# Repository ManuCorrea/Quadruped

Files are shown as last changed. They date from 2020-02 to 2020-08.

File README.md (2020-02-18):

# RL Quadruped
This project is a robotic platform to use for education, development and research. 
Objectives: **democratize robotics** and **sim-to-real research**.



## Installation

If using stable baselines:

```
sudo apt-get update && sudo apt-get install cmake libopenmpi-dev python3-dev zlib1g-dev
```

```
pip3 install -r requeriments.txt
```

## Bill of Materials
* Nvidia Jetson Nano
* Arduino Mega
* TinyFPGA BX
* 12 x micro gear dc motors with encoders
* 2 x servos
* ADNS 3080 optical flow sensor
* GY-521
* 7-12V LiPo battery
* 10 x 3D printer endstops
### Tools
* 3D printer
* Soledering iron and solder wire
* M3 screws, nuts and self-locking nuts

## Building

For details and images you can check my [hackster project](https://www.hackster.io/_ManuCorrea_/rl-quadruped-0afbc3)

## Contributing
Pull requests are welcome. For major changes, please open an issue first to discuss what you would like to change.

Feel free to [contact me](https://twitter.com/_ManuCorrea_) directly if you are interested in the project.

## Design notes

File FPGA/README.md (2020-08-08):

# Description
Current used board is a TinyFPGA BX. For a efficient and fast motor control we should make a module based on a bigger FPGA/CPLD.

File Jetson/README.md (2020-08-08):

# Description
Here you have different functions to communicate with Arduino Mega by USB Serial.

## TODO Upgrades
- [ ] Check extreme cases and robustness.
- [ ] Add simplier functions (here and in Arduino) to ask for a certain joint/s instead of all
- [ ] Check how SPI performs and implement it in SPI if it has better results.

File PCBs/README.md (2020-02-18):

# Description
In this folder there will be the KiCad projects of the differents PCBs.

## TODO Upgrades
- [ ] Use a different motor controller IC with PWM to control them with speed variation and implement it in a PCB design.
- [ ] Create PCB for plugging all endstops instead of the protoboard.
- [ ] Create an unique PCB with all electronics.

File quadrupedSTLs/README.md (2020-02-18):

For all parts 0.3 mm layer height is okay and much faster than 0.2 mm.

For gears I recommend using 0.2 mm but each printer is different so you will have to tweak it according to your printer.

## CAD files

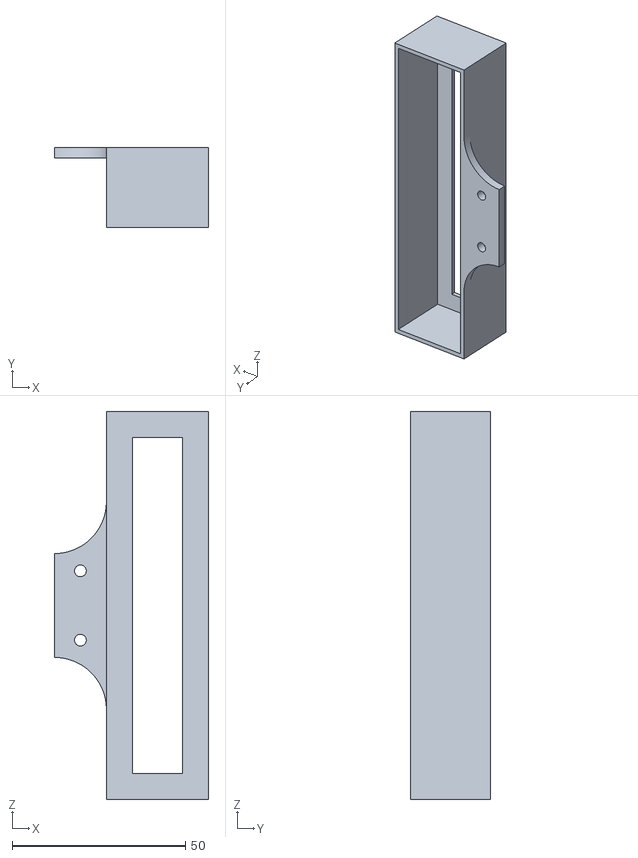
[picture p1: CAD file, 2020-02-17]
quadrupedSTLs/Extras/12V batteryHolder.stl
44.5 x 23.0 x 112.0

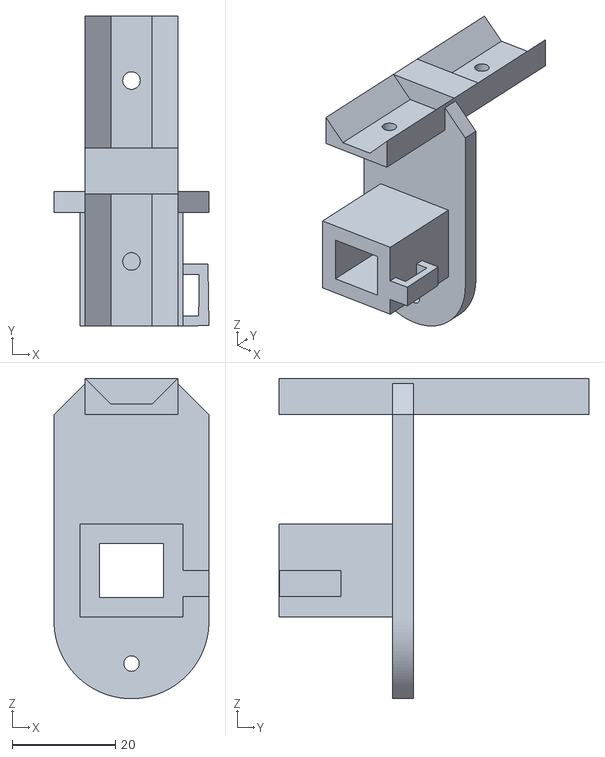
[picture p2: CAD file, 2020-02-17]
quadrupedSTLs/shoulderHorizontal.stl
30.0 x 60.0 x 62.0

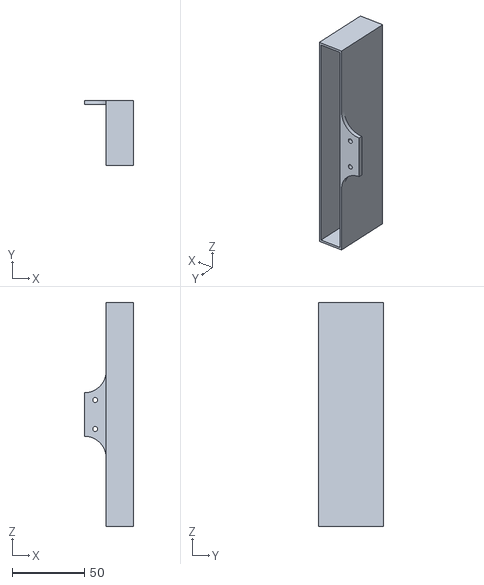
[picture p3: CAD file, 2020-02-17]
quadrupedSTLs/Extras/xiaomiBateryHolder.stl
34.0 x 45.0 x 154.5

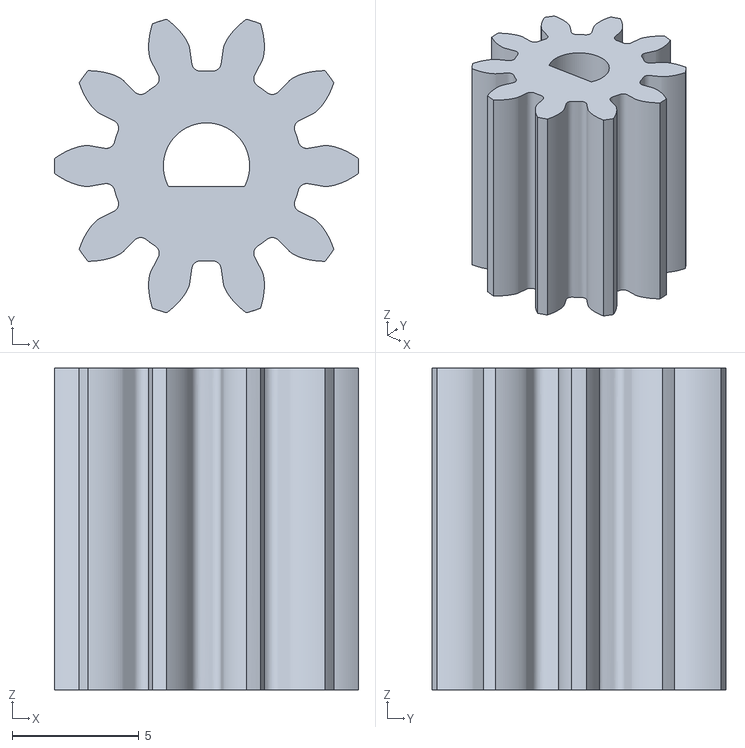
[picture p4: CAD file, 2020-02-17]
quadrupedSTLs/shoulderVerticalGear.stl
12.0 x 11.6 x 12.7

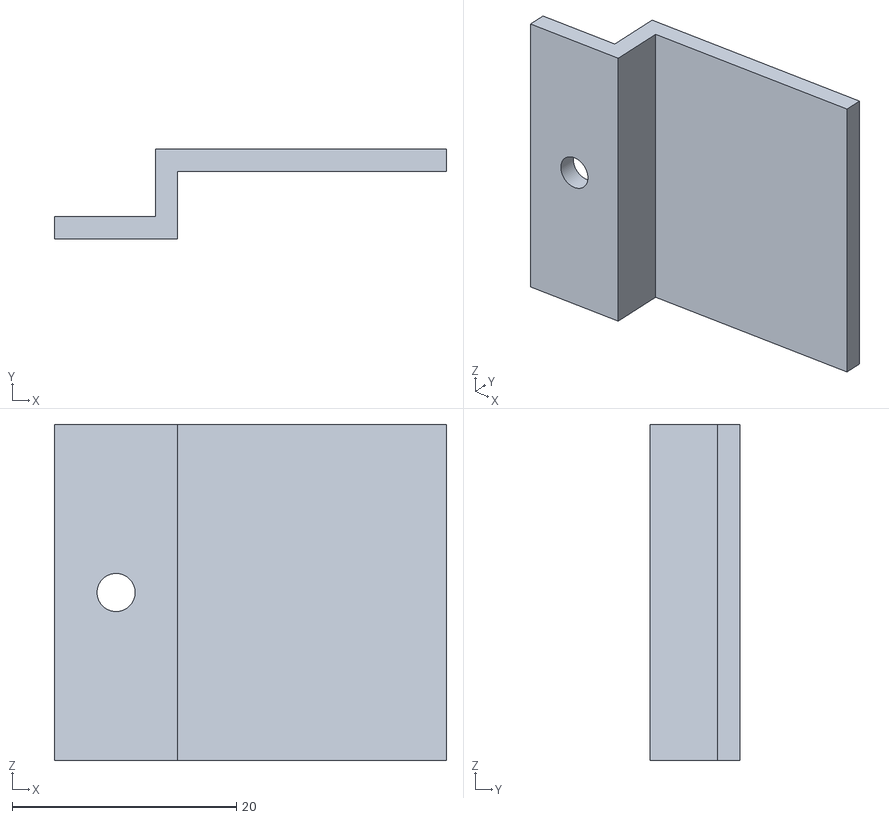
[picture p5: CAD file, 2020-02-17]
quadrupedSTLs/Extras/ADNS_2_servoHolder.stl
35.0 x 8.00 x 30.0

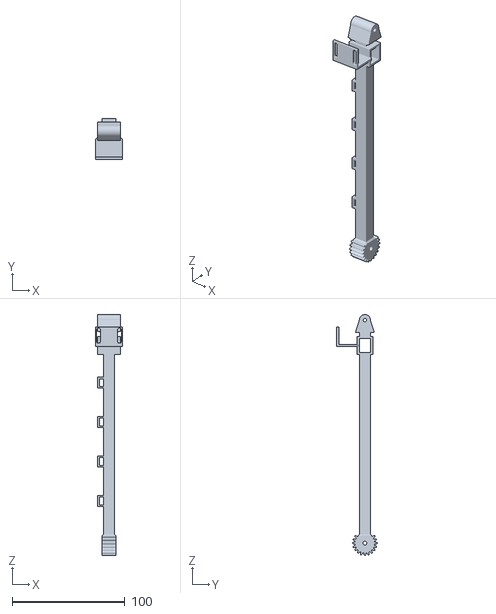
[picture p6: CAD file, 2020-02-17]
quadrupedSTLs/femur.stl
24.0 x 36.0 x 213.7

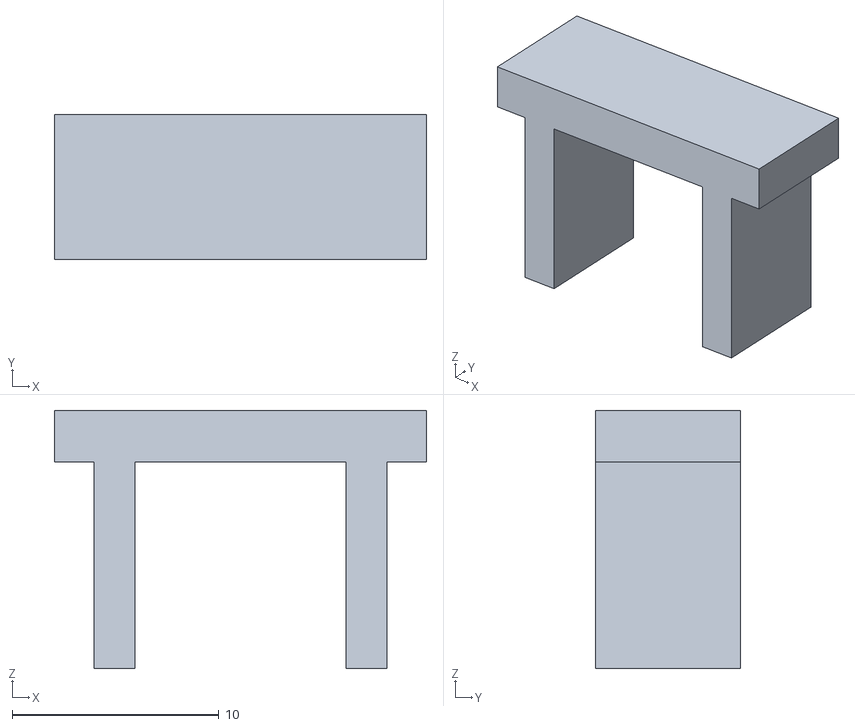
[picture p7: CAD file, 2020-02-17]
quadrupedSTLs/Extras/tibiaEndStop.stl
18.0 x 7.00 x 12.5

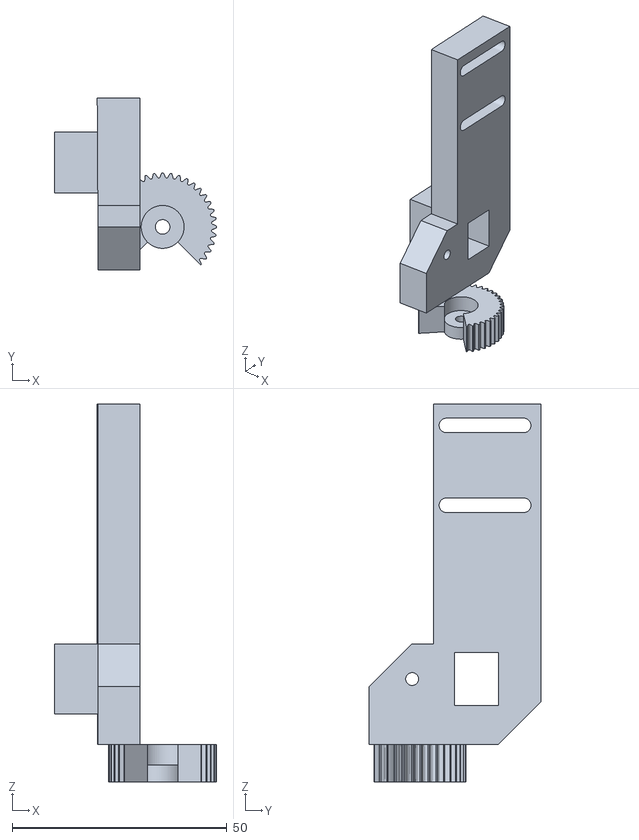
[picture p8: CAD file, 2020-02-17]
quadrupedSTLs/shoulderVertical.stl
37.8 x 40.0 x 88.1

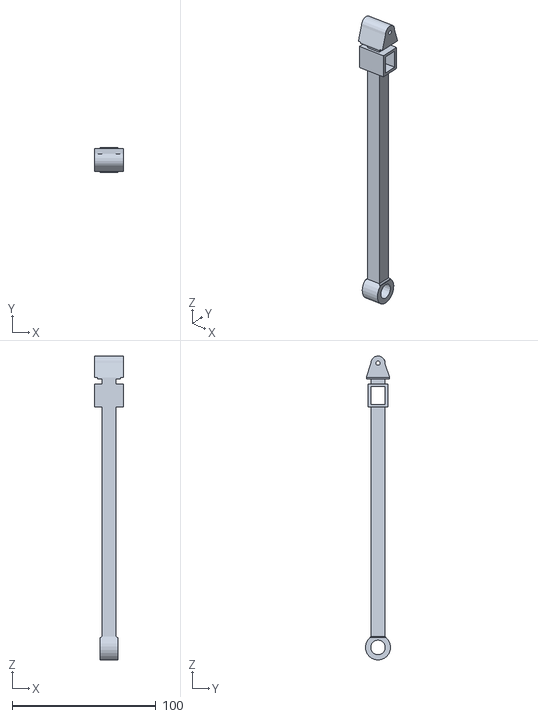
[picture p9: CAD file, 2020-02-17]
URDF_Quadruped/STLs/femurSimplificado.stl
20.0 x 17.5 x 211.5

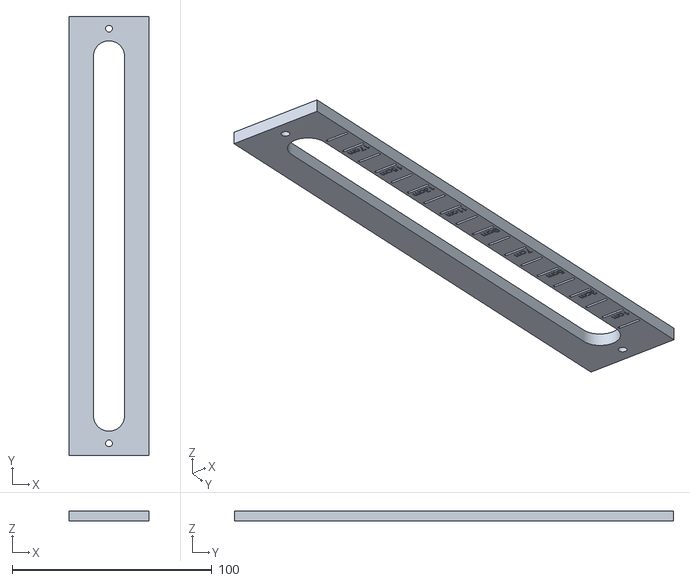
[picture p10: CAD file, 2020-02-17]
quadrupedSTLs/Extras/ADNS_tester.stl
40.0 x 220.0 x 5.00

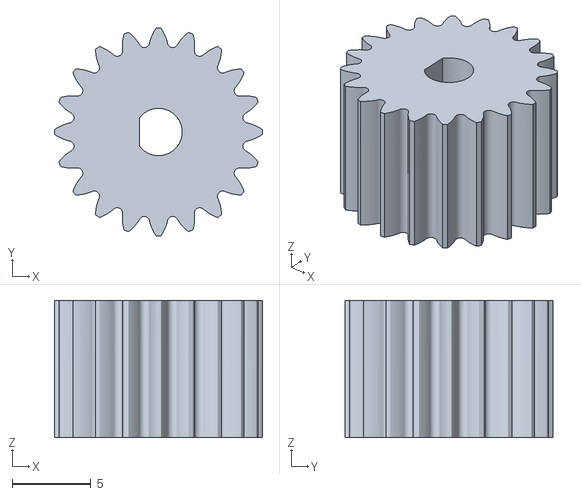
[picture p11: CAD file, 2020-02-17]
quadrupedSTLs/shoulderHorizontalGear.stl
13.2 x 13.2 x 8.70

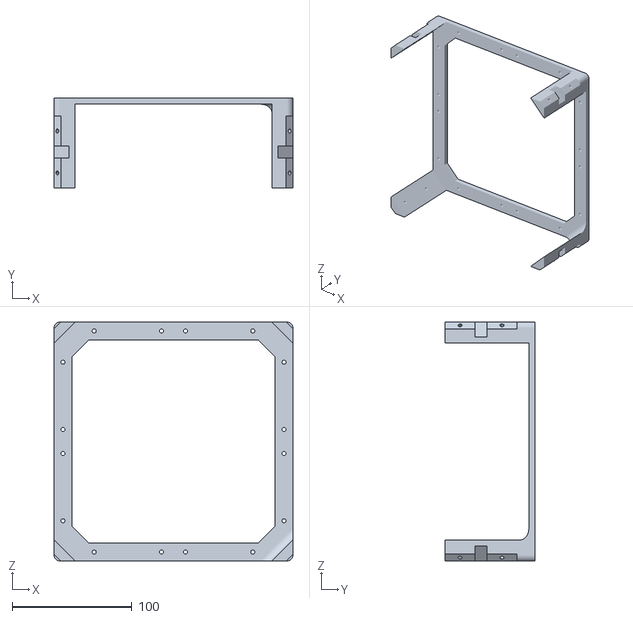
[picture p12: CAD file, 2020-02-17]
quadrupedSTLs/Body.stl
200.0 x 75.0 x 200.0

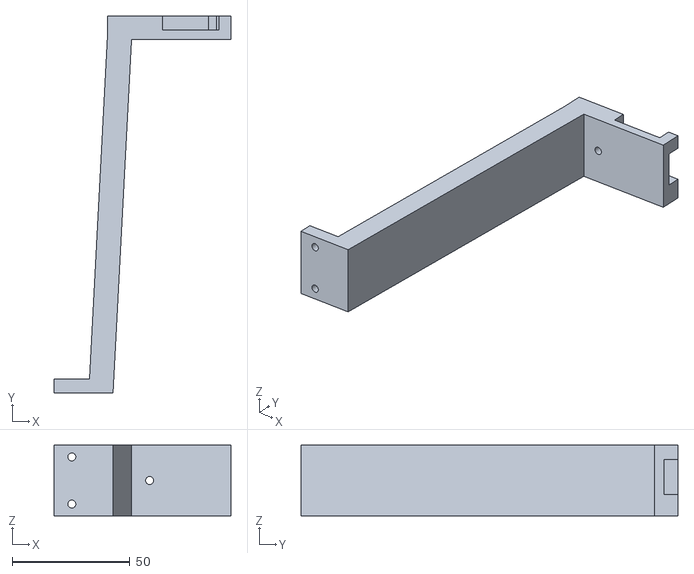
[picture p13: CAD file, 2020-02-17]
quadrupedSTLs/Extras/bodyADNS.stl
75.0 x 160.0 x 30.0

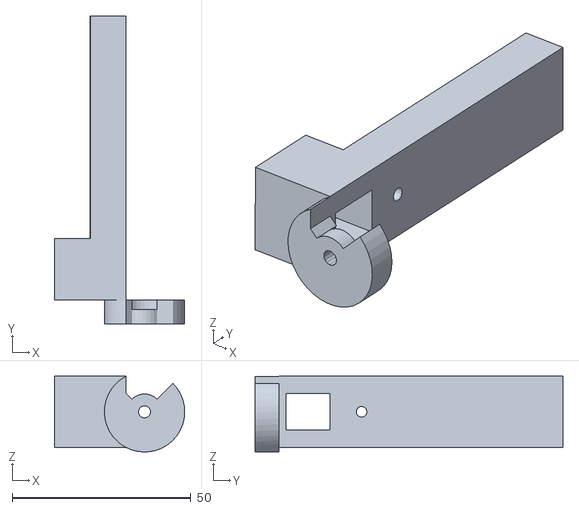
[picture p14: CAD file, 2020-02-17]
URDF_Quadruped/STLs/soporteFemur Simplificado.stl
36.5 x 86.1 x 21.2

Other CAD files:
URDF_Quadruped/STLs/HombroSoporte_m.stl
URDF_Quadruped/STLs/femurSimplificado_m.stl
URDF_Quadruped/STLs/Tibia_m.stl
URDF_Quadruped/STLs/Femur_m.stl
URDF_Quadruped/STLs/Cuerpo.stl
URDF_Quadruped/STLs/Cuerpo_m.stl
URDF_Quadruped/STLs/Femur.stl
URDF_Quadruped/STLs/HombroSoporte.stl
URDF_Quadruped/STLs/Tibia.stl
quadrupedSTLs/Extras/ADNS_2.stl
quadrupedSTLs/femurGear.stl
quadrupedSTLs/tibia.stl

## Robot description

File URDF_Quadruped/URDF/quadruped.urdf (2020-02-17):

<?xml version="1.0"?>
<robot name="Quadruped">
    <link name="base_link">
        <inertial>
            <origin xyz="0.0 0.0 0.016" rpy="0.0 0.0 0.0"/>
            <mass value="0.075"/>
            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
        </inertial>
        
        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
        
        <origin xyz="0 0 0" rpy="0 0 0"/>

        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

    </link>

    <link name="shoulder1">
        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
    </link>

    <link name="shoulder2">
        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
    </link>

    <link name="shoulder3">
        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
    </link>

    <link name="shoulder4">
        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
    </link>

    <link name="rot_shoulder1">
        <inertial>
            <origin xyz="-0.010 0.040 0.0" rpy="0.0 0.0 0.0"/>
            <mass value="0.016"/>
            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
        </inertial>
        
        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
    </link>

    <link name="rot_shoulder2">
        <inertial>
            <origin xyz="-0.010 0.040 0.0" rpy="0.0 0.0 0.0"/>
            <mass value="0.016"/>
            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
        </inertial>
        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
    </link>

    <link name="rot_shoulder3">
        <inertial>
            <origin xyz="-0.010 0.040 0.0" rpy="0.0 0.0 0.0"/>
            <mass value="0.016"/>
            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
        </inertial>
        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
    </link>

    <link name="rot_shoulder4">
        <inertial>
            <origin xyz="-0.010 0.040 0.0" rpy="0.0 0.0 0.0"/>
            <mass value="0.016"/>
            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
        </inertial>
        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
    </link>

    <joint name="S1_rot" type="revolute">
        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
        <origin xyz="0.0 -0.026 -0.0481" rpy="0.0 3.14 0.0"/>
        <parent link="shoulder1"/>
        <child link="rot_shoulder1"/>
        <axis xyz="0.0 1.0 0.0"/>
        <limit effort="0" velocity="1.0" lower="-1.57" upper="1.57" />
    </joint>   

    <joint name="S2_rot" type="revolute">
        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
        <origin xyz="0.0 -0.026 -0.0481" rpy="0.0 3.14 0.0"/>
        <parent link="shoulder2"/>
        <child link="rot_shoulder2"/>
        <axis xyz="0.0 1.0 0.0"/>
        <limit effort="0" velocity="1.0" lower="-1.57" upper="1.57" />
    </joint>   

    <joint name="S3_rot" type="revolute">
        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
        <origin xyz="0.0 -0.026 -0.0481" rpy="0.0 3.14 0.0"/>
        <parent link="shoulder3"/>
        <child link="rot_shoulder3"/>
        <axis xyz="0.0 1.0 0.0"/>
        <limit effort="0" velocity="1.0" lower="-1.57" upper="1.57" />
    </joint>   

    <joint name="S4_rot" type="revolute">
        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
        <origin xyz="0.0 -0.026 -0.0481" rpy="0.0 3.14 0.0"/>
        <parent link="shoulder4"/>
        <child link="rot_shoulder4"/>
        <axis xyz="0.0 1.0 0.0"/>
        <limit effort="0" velocity="1.0" lower="-1.57" upper="1.57" />
    </joint>   

    
    <link name="femur1">
        <inertial>
            <origin xyz="0.006 0.0 0.104" rpy="0.0 0.0 0.0"/>
            <mass value="0.020"/>
            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
        </inertial>
        
        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
    </link>

    <link name="femur2">
        <inertial>
            <origin xyz="0.006 0.0 0.104" rpy="0.0 0.0 0.0"/>
            <mass value="0.020"/>
            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
        </inertial>
        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
    </link>

    <link name="femur3">
        <inertial>
            <origin xyz="0.006 0.0 0.104" rpy="0.0 0.0 0.0"/>
            <mass value="0.020"/>
            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
        </inertial>
        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
    </link>

    <link name="femur4">
        <inertial>
            <origin xyz="0.006 0.0 0.104" rpy="0.0 0.0 0.0"/>
            <mass value="0.020"/>
            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
        </inertial>
        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
    </link>

    <joint name="rot_femur1" type="revolute">
        <origin xyz="-0.00525 0.0298 0.0" rpy="0.0 0 0.0"/>
        <parent link="rot_shoulder1"/>
        <child link="femur1"/>
        <axis xyz="1.0 0.0 0.0"/>
        <limit effort="0" velocity="1.0" lower="-0.7" upper="0.7" />
    </joint>

    <joint name="rot_femur2" type="revolute">
        <origin xyz="-0.00525 0.0298 0.0" rpy="0.0 0 0.0"/>
        <parent link="rot_shoulder2"/>
        <child link="femur2"/>
        <axis xyz="1.0 0.0 0.0"/>
        <limit effort="0" velocity="1.0" lower="-0.7" upper="0.7" />
    </joint>

    <joint name="rot_femur3" type="revolute">
        <origin xyz="-0.00525 0.0298 0.0" rpy="0.0 0 0.0"/>
        <parent link="rot_shoulder3"/>
        <child link="femur3"/>
        <axis xyz="1.0 0.0 0.0"/>
        <limit effort="0" velocity="1.0" lower="-0.7" upper="0.7" />
    </joint>

    <joint name="rot_femur4" type="revolute">
        <origin xyz="-0.00525 0.0298 0.0" rpy="0.0 0 0.0"/>
        <parent link="rot_shoulder4"/>
        <child link="femur4"/>
        <axis xyz="1.0 0.0 0.0"/>
        <limit effort="0" velocity="1.0" lower="-0.7" upper="0.7" />
    </joint>

    <link name="tibia1">
        <inertial>
            <origin xyz="0.0 0.0 -0.090" rpy="0.0 0.0 0.0"/>
            <mass value="0.022"/>
            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
        </inertial>
        
        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
    </link>

    <link name="tibia2">
        <inertial>
            <origin xyz="0.0 0.0 -0.090" rpy="0.0 0.0 0.0"/>
            <mass value="0.022"/>
            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
        </inertial>
        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
    </link>

    <link name="tibia3">
        <inertial>
            <origin xyz="0.0 0.0 -0.090" rpy="0.0 0.0 0.0"/>
            <mass value="0.022"/>
            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
        </inertial>
        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
    </link>

    <link name="tibia4">
        <inertial>
            <origin xyz="0.0 0.0 -0.090" rpy="0.0 0.0 0.0"/>
            <mass value="0.022"/>
            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
        </inertial>
        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
    </link>

    <joint name="knee1" type="revolute">
        <origin xyz="0.00635 0.0 0.197" rpy="0.0 3.14 0.0"/>
        <parent link="femur1"/>
        <child link="tibia1"/>
        <axis xyz="1.0 0.0 0.0"/>
        <limit effort="0" velocity="1.0" lower="-1.57" upper="0.8" />
    </joint>

    <joint name="knee2" type="revolute">
        <origin xyz="0.00635 0.0 0.197" rpy="0.0 3.14 0.0"/>
        <parent link="femur2"/>
        <child link="tibia2"/>
        <axis xyz="1.0 0.0 0.0"/>
        <limit effort="0" velocity="1.0" lower="-1.57" upper="0.8" />
    </joint>

    <joint name="knee3" type="revolute">
        <origin xyz="0.00635 0.0 0.197" rpy="0.0 3.14 0.0"/>
        <parent link="femur3"/>
        <child link="tibia3"/>
        <axis xyz="1.0 0.0 0.0"/>
        <limit effort="0" velocity="1.0" lower="-1.57" upper="0.8" />
    </joint>

    <joint name="knee4" type="revolute">
        <origin xyz="0.00635 0.0 0.197" rpy="0.0 3.14 0.0"/>
        <parent link="femur4"/>
        <child link="tibia4"/>
        <axis xyz="1.0 0.0 0.0"/>
        <limit effort="0" velocity="1.0" lower="-1.57" upper="0.8" />
    </joint>



    <joint name="base1" type="fixed">
        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
        <origin xyz="0.097172 0.097172 -0.0275" rpy="1.57 0.0 -0.785"/>
        <parent link="base_link"/>
        <child link="shoulder1"/>
    </joint>

    <joint name="base2" type="fixed">
        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
        <origin xyz="0.097172 -0.097172 -0.0275" rpy="1.57 0.0 -2.356"/>
        <parent link="base_link"/>
        <child link="shoulder2"/>
    </joint>

    <joint name="base3" type="fixed">
        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
        <origin xyz="-0.097172 -0.097172 -0.0275" rpy="1.57 0.0 2.356"/>
        <parent link="base_link"/>
        <child link="shoulder3"/>
    </joint>

    <joint name="base4" type="fixed">
        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
        <origin xyz="-0.097172 0.097172 -0.0275" rpy="1.57 0.0 0.785"/>
        <parent link="base_link"/>
        <child link="shoulder4"/>
    </joint>
</robot>

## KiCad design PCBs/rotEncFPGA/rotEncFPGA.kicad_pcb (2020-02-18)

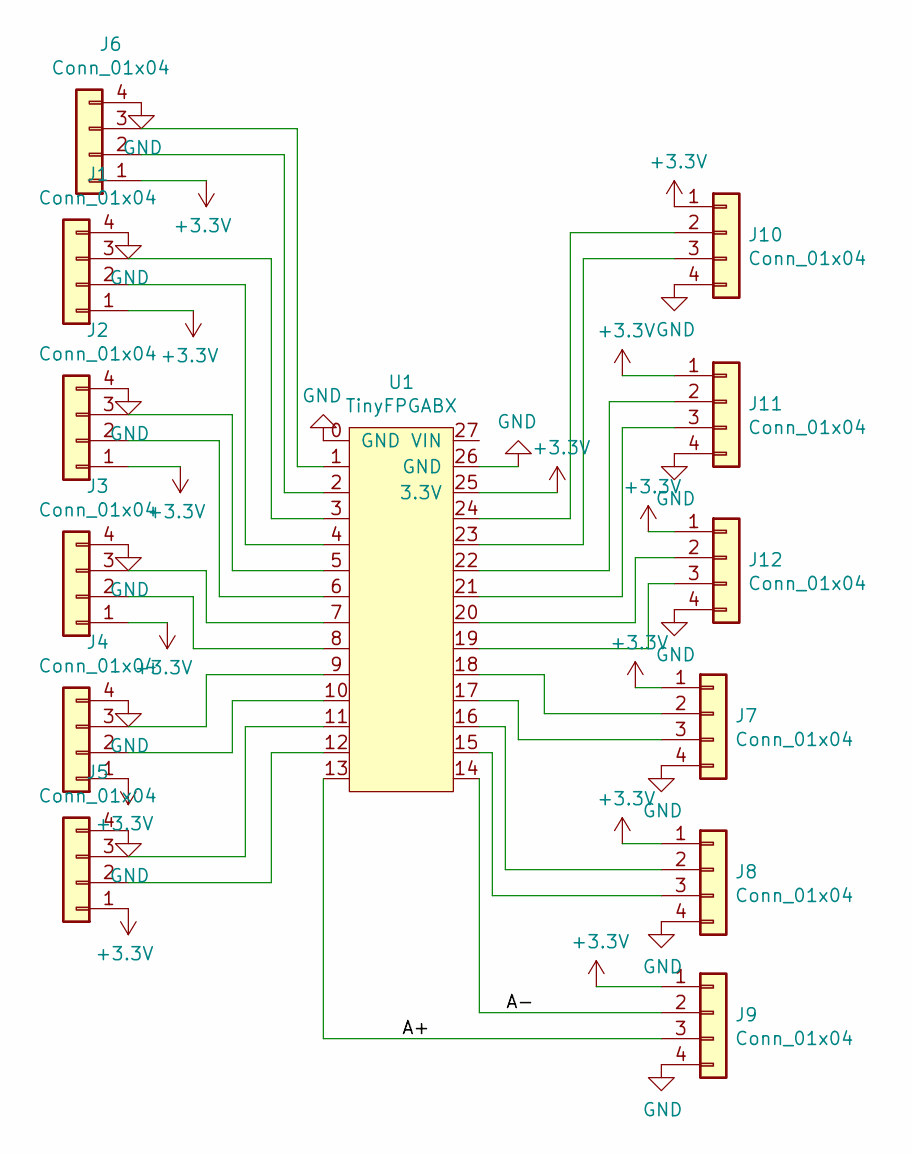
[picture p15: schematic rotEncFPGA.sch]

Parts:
J1, J2, J3, J4, J5, J6, J7, J8, J9, J10, J11, J12: Conn_01x04; PinSocket_1x04_P2.54mm_Vertical
U1: TinyFPGABX; tinyFPGABX

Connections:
+3V3: J1.1, J2.1, J3.1, J4.1, J5.1, J6.1, J7.1, J8.1, J9.1, J10.1, J11.1, J12.1, U1.25 (3.3V); also elsewhere on the board
/A+: J9.3, U1.13; also elsewhere on the board
/A-: J9.2, U1.14; also elsewhere on the board
GND: J1.4, J2.4, J3.4, J4.4, J5.4, J6.4, J7.4, J8.4, J9.4, J10.4, J11.4, J12.4, U1.0 (GND), U1.26 (GND); also elsewhere on the board
unnamed 4: J1.2, U1.4; also elsewhere on the board
unnamed 5: J1.3, U1.3; also elsewhere on the board
unnamed 6: J2.2, U1.6; also elsewhere on the board
unnamed 7: J2.3, U1.5; also elsewhere on the board
unnamed 8: J3.2, U1.8; also elsewhere on the board
unnamed 9: J3.3, U1.7; also elsewhere on the board
unnamed 10: J4.2, U1.10; also elsewhere on the board
unnamed 11: J4.3, U1.9; also elsewhere on the board
unnamed 12: J5.2, U1.12; also elsewhere on the board
unnamed 13: J5.3, U1.11; also elsewhere on the board
unnamed 14: J6.2, U1.2; also elsewhere on the board
unnamed 15: J6.3, U1.1; also elsewhere on the board
unnamed 16: J7.2, U1.18; also elsewhere on the board
unnamed 17: J7.3, U1.17; also elsewhere on the board
unnamed 18: J8.2, U1.16; also elsewhere on the board
unnamed 19: J8.3, U1.15; also elsewhere on the board
unnamed 20: J10.2, U1.24; also elsewhere on the board
unnamed 21: J10.3, U1.23; also elsewhere on the board
unnamed 22: J11.2, U1.22; also elsewhere on the board
unnamed 23: J11.3, U1.21; also elsewhere on the board
unnamed 24: J12.2, U1.20; also elsewhere on the board
unnamed 25: J12.3, U1.19; also elsewhere on the board

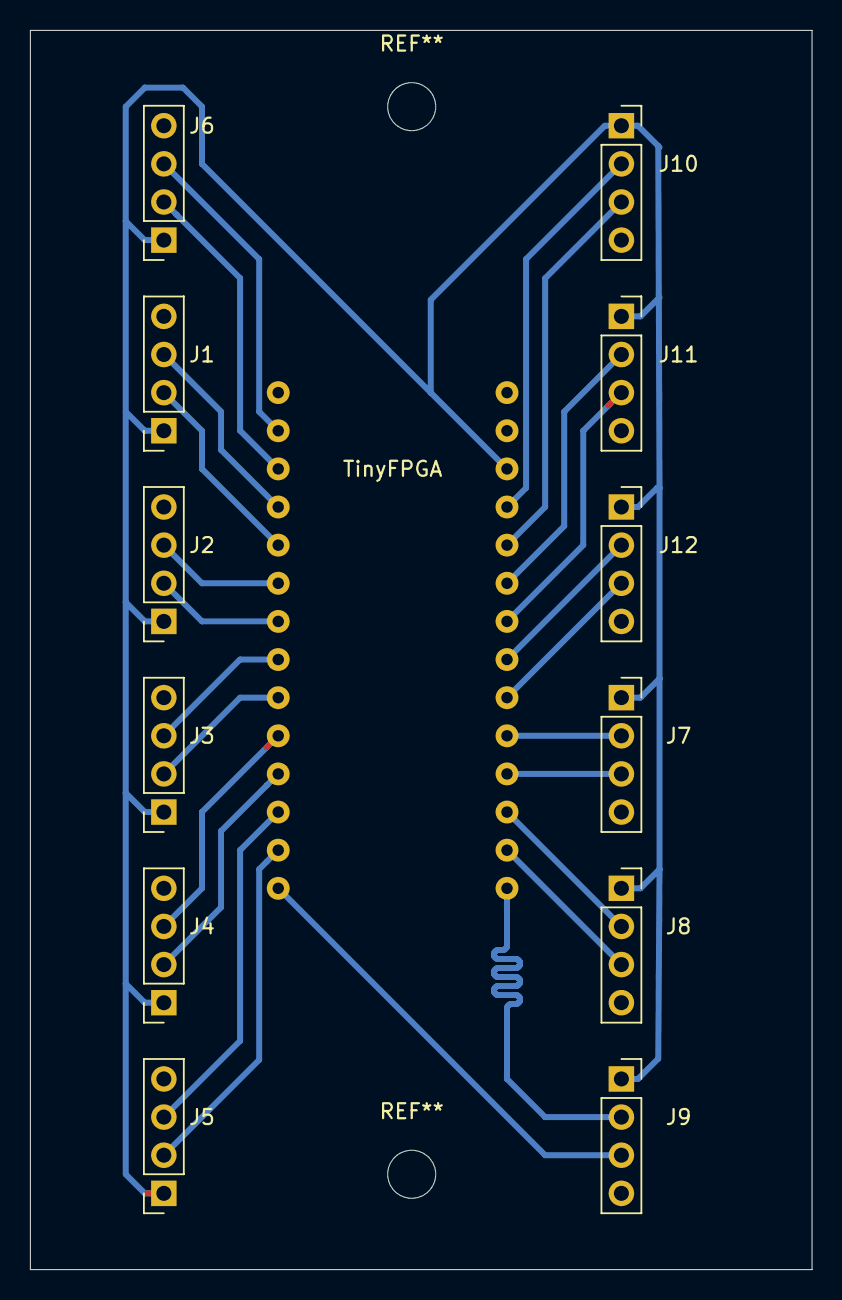
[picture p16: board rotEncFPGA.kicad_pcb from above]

Board: 2 copper layers, 52.1 x 82.5 mm, 13 parts (0 on the bottom side), 26 nets.

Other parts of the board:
TinyFPGA: TinyFPGABX; tinyFPGABX

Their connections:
+3V3: TinyFPGA.25; also elsewhere on the board
/A+: TinyFPGA.13; also elsewhere on the board
/A-: TinyFPGA.14; also elsewhere on the board
GND: TinyFPGA.0, TinyFPGA.26; also elsewhere on the board
unnamed 4: TinyFPGA.4; also elsewhere on the board
unnamed 5: TinyFPGA.3; also elsewhere on the board
unnamed 6: TinyFPGA.6; also elsewhere on the board
unnamed 7: TinyFPGA.5; also elsewhere on the board
unnamed 8: TinyFPGA.8; also elsewhere on the board
unnamed 9: TinyFPGA.7; also elsewhere on the board
unnamed 10: TinyFPGA.10; also elsewhere on the board
unnamed 11: TinyFPGA.9; also elsewhere on the board
unnamed 12: TinyFPGA.12; also elsewhere on the board
unnamed 13: TinyFPGA.11; also elsewhere on the board
unnamed 14: TinyFPGA.2; also elsewhere on the board
unnamed 15: TinyFPGA.1; also elsewhere on the board
unnamed 16: TinyFPGA.18; also elsewhere on the board
unnamed 17: TinyFPGA.17; also elsewhere on the board
unnamed 18: TinyFPGA.16; also elsewhere on the board
unnamed 19: TinyFPGA.15; also elsewhere on the board
unnamed 20: TinyFPGA.24; also elsewhere on the board
unnamed 21: TinyFPGA.23; also elsewhere on the board
unnamed 22: TinyFPGA.22; also elsewhere on the board
unnamed 23: TinyFPGA.21; also elsewhere on the board
unnamed 24: TinyFPGA.20; also elsewhere on the board
unnamed 25: TinyFPGA.19; also elsewhere on the board

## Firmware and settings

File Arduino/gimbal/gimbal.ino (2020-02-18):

#include <Wire.h>
#include <Adafruit_PWMServoDriver.h>

Adafruit_PWMServoDriver pwm = Adafruit_PWMServoDriver();

#define SERVOMIN  150 // this is the 'minimum' pulse length count (out of 4096)
#define SERVOMAX  600 // this is the 'maximum' pulse length count (out of 4096)
int pulselength;

const int MPU_addr = 0x68; // AD0 low. look at "9.2 I2C Interface" in datasheet
int16_t AcX, AcY, AcZ; // 16bit precision from MPU 6000/6050
int minVal = 265; int maxVal = 402;

double x; double y; double z;

void setup_MPU(){ // Process needed to setup MPU
  Wire.begin();
  Wire.beginTransmission(MPU_addr);
  Wire.write(0x6B);
  Wire.write(0);
  Wire.endTransmission(true);
}

void XYdata(double *x, double *y){ // Function to get x and y angles from MPU
  Wire.beginTransmission(MPU_addr);
  Wire.write(0x3B);
  Wire.endTransmission(false);
  Wire.requestFrom(MPU_addr, 6, true);
  AcX = Wire.read() << 8 | Wire.read();
  AcY = Wire.read() << 8 | Wire.read();
  AcZ = Wire.read() << 8 | Wire.read();
  int xAng = map(AcX, minVal, maxVal, -90, 90);
  int yAng = map(AcY, minVal, maxVal, -90, 90);
  int zAng = map(AcZ, minVal, maxVal, -90, 90);

  *x = RAD_TO_DEG * (atan2(-yAng, -zAng) + PI);
  *y = RAD_TO_DEG * (atan2(-xAng, -zAng) + PI);
}

void setup() {
  setup_MPU();
  pwm.begin();
  
  pwm.setPWMFreq(60);  // Analog servos run at ~60 Hz updates

  delay(10);
} 
void loop() {
  // TODO: add MPU interruptions for more efficient process
  XYdata(&x, &y);
  
  if(x>0 && x<90){
    pulselength = map(int(map(x,90, 0, 0, 90)), 0, 180, SERVOMIN, SERVOMAX);
    pwm.setPWM(1, 0, pulselength);
  }else if(x<360 && x>270){
    pulselength = map(int(map(x,360, 275, 90, 180)), 0, 180, SERVOMIN, SERVOMAX);
    pwm.setPWM(1, 0, pulselength);
  }

  if(y>0 && y<90){
    pulselength = map(int(map(y,90, 0, 180, 90)), 0, 180, SERVOMIN, SERVOMAX);
    pwm.setPWM(0, 0, pulselength);
  }else if(y<360 && y>270){
    pulselength = map(int(map(y,360, 275, 90, 0)), 0, 180, SERVOMIN, SERVOMAX);
    pwm.setPWM(0, 0, pulselength);
  }
  delay(100);
}

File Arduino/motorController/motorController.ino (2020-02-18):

/*
 * Valid with L293
 */

int const nMotors = 12;

int motorPins[nMotors];

void setupMotorControl(int nMotors){
  int numberOfMotor = 0;
  // I started at pin 22 but you can start at anyone taking care of not having conflicts with others
  for (int i=22; i<22+nMotors*2; i++){
    pinMode(i, OUTPUT);
    if(i%2 == 0){                   // Each motor needs 2 pins for controlling
      motorPins[numberOfMotor] = i; // we save n knowing that n+1 will be the other
      numberOfMotor ++;
    }
  }
}

// motorDirection negative Right | 0 stop | positive Left 
void motorControl(int motor, int motorDirection){
  if (motorDirection<0){
    digitalWrite(motorPins[motor], LOW);
    digitalWrite(motorPins[motor]+1, HIGH);
  } else if((motorDirection>0)){
    digitalWrite(motorPins[motor], HIGH);
    digitalWrite(motorPins[motor]+1, LOW);
  }else{
    digitalWrite(motorPins[motor], LOW);
    digitalWrite(motorPins[motor]+1, LOW);
  }
}

void setup() {
  // put your setup code here, to run once:

}

void loop() {
  // put your main code here, to run repeatedly:

}

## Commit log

2020-01-24 Added motorController but not tested, need to finish PCB.
2020-02-17 Added ROS package with URDF file and simplified STLs of Quadruped.
    [Cuerpo.stl, Cuerpo_m.stl, Femur.stl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]
2020-02-17 Added quadruped STLs files.
    [12V batteryHolder.stl, ADNS_2.stl, ADNS_2_servoHolder.stl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]
2020-02-18 TinyFPGA PCB added.
    [rotEncFPGA.kicad_pcb, rotEncFPGA.sch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]
2020-02-18 Added main jetson script for taking data and give orders.
2020-02-18 Added READMEs and Arduino program with functions to communicate with Jetson by Serial.
